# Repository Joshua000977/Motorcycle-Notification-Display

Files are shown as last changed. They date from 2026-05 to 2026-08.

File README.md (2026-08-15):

# Motorcycle Notification & TPMS Display

A compact motorcycle display system built around an ESP32-C3 and an Android application. It presents selected phone notifications, incoming-call information, phone battery status, and tire-pressure data on a handlebar-mounted TFT display.

The Android phone acts as the communication hub: it receives phone events and BLE TPMS data, filters and formats the relevant information, and forwards compact messages to the ESP32. The ESP32 handles parsing, warning logic, persistence, and display rendering.

> **Project status:** Active prototype. Phone-to-display BLE communication, notification rendering, and the embedded display foundation are implemented. TPMS integration and reliable background reconnection while the phone is locked are ongoing development areas.

## Features

### Implemented

- ESP32-C3 BLE peripheral named `MotoNotifyDisplay`
- Android-to-ESP32 BLE connection
- Display of selected phone notifications
- Incoming-call information
- Phone battery updates
- Compact custom text protocol
- TFT display rendering and idle screen
- Persistent configuration on the ESP32
- OTA firmware updates over Wi-Fi
- Tire-pressure warning states in the embedded display logic

### In Development

- Stable Android background operation through a foreground service
- Automatic reconnection when the ESP32 restarts while the phone is locked
- Simultaneous Android BLE connections to the ESP32 and both TPMS sensors
- Reliable pressure and temperature decoding for front and rear sensors
- Forwarding live TPMS data to the ESP32
- Android configuration UI for target pressures and warning thresholds
- Final weatherproof motorcycle enclosure and power installation

### Planned

- Per-app notification filters
- Multiple motorcycle profiles
- TPMS and temperature history
- External warning LEDs or audible alerts
- Navigation information
- Ride statistics

## System Overview

```mermaid
flowchart TD
    PHONE["Android phone"] --> APP["Android application"]
    FRONT["Front TPMS sensor"] --> APP
    REAR["Rear TPMS sensor"] --> APP
    APP --> ESP["ESP32-C3 display unit"]
    ESP --> TFT["TFT display"]
```

The phone handles Android permissions, notification access, calls, background execution, and BLE central connections. The ESP32 remains focused on receiving compact messages and presenting information clearly while riding.

See [docs/architecture.md](docs/architecture.md) for component responsibilities, BLE flows, message handling, reconnect behavior, and safety considerations.

## Hardware

| Component | Purpose |
|---|---|
| Seeed Studio ESP32-C3 SuperMini | BLE receiver and display controller |
| TFT display | Rider-facing interface |
| Front BLE TPMS sensor | Front pressure and temperature |
| Rear BLE TPMS sensor | Rear pressure and temperature |
| Android phone | Notification, call, TPMS, and BLE hub |
| Motorcycle power supply | Powers the embedded display unit |

## Technology

### Embedded Firmware

- C++
- Arduino framework
- PlatformIO
- NimBLE
- TFT_eSPI
- Persistent configuration storage
- Arduino OTA

### Android Application

- Kotlin
- Android BLE APIs
- `BluetoothGatt`
- `NotificationListenerService`
- Foreground-service architecture for reliable background communication
- Notification filtering and message formatting

### Communication

- Bluetooth Low Energy
- Custom text-based message protocol
- Android phone as BLE central
- ESP32-C3 as BLE peripheral

## BLE Message Protocol

The protocol uses short, human-readable messages. A prefix identifies the message type and the remaining text contains its value.

Examples:

```text
CALL:John Doe
NOTIFY:WhatsApp: Alex
BAT:58
FRONT:2.30
REAR:2.20
FTEMP:28
RTEMP:31
```

| Prefix | Meaning | Example value |
|---|---|---|
| `CALL` | Incoming call information | Caller name or number |
| `NOTIFY` | Selected notification | Application and message summary |
| `BAT` | Phone battery percentage | `58` |
| `FRONT` | Front tire pressure | `2.30` bar |
| `REAR` | Rear tire pressure | `2.20` bar |
| `FTEMP` | Front tire temperature | `28` °C |
| `RTEMP` | Rear tire temperature | `31` °C |

The text format is easy to inspect during development and simple to parse on the ESP32. A versioned binary protocol can be introduced later if message size or throughput becomes a real limitation.

## Tire-Pressure Warning Logic

Pressure warnings are calculated relative to configurable front and rear reference pressures.

Default reference values:

| Tire | Reference pressure |
|---|---:|
| Front | 2.5 bar |
| Rear | 2.8 bar |

| Status | Condition |
|---|---|
| Normal | Pressure is within the configured warning limits |
| Warning low | More than 10% below the reference pressure |
| Critical low | Front more than 15% low; rear more than 20% low |
| Warning high | More than 15% above the reference pressure |
| Critical high | More than 25% above the reference pressure |
| Critical | Pressure is less than or equal to 0 bar |

The display uses a simple color hierarchy:

| State | Color |
|---|---|
| Normal | White |
| Warning | Yellow |
| Critical | Red |

Reference pressures and thresholds must be configured for the motorcycle, tires, load, and manufacturer recommendations used in the real installation.

## Building the Firmware

1. Open the firmware project in Visual Studio Code with PlatformIO.
2. Select the configured ESP32-C3 environment.
3. Configure the display pins and TFT_eSPI setup for the installed hardware.
4. Build and upload the firmware over USB.
5. Configure Wi-Fi only if OTA updates are required.

After the first USB upload, later firmware versions can be installed through Arduino OTA when the device and development computer are on the same network.

## Building the Android Application

1. Open the Android project in Android Studio.
2. Grant the required Bluetooth and notification permissions.
3. Enable notification access for the application.
4. Build and install the application on the Android phone.
5. Connect the app to `MotoNotifyDisplay`.
6. Configure the front and rear TPMS sensors when TPMS support is enabled.

Android background restrictions vary between phone manufacturers. Foreground-service behavior, battery optimization, and BLE reconnection must be tested on the actual phone used on the motorcycle.

## Development Priorities

1. Finish the foreground service and locked-phone reconnection behavior.
2. Complete and verify both TPMS sensor connections.
3. Validate pressure and temperature values against known measurements.
4. Finish the Android configuration interface.
5. Improve display layouts and connection indicators.
6. Test reconnects, sensor loss, invalid values, and low battery conditions.
7. Build and validate the weatherproof motorcycle installation.

## Safety

This is a personal prototype and not a certified tire-pressure monitoring system. It should supplement, not replace:

- Manual pressure checks with a reliable gauge
- Motorcycle manufacturer pressure recommendations
- Regular tire inspection
- Approved motorcycle instruments and warning systems

The interface should not encourage interaction while riding. Alerts must be readable at a glance, and configuration should be performed while stationary.

## License

This project is licensed under the [MIT License](LICENSE)

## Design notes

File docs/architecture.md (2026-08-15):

# Architecture

This document describes the architecture of the Motorcycle Notification & TPMS Display. It separates the working embedded foundation from background-reconnection and TPMS functionality that is still being completed.

## 1. Design Goals

- Present essential information without requiring the rider to handle the phone.
- Keep the handlebar unit small and computationally simple.
- Use the Android phone for operating-system events and BLE sensor management.
- Keep the communication protocol easy to debug.
- Continue displaying the latest valid data when one source temporarily disconnects.
- Make warning states clear without creating unnecessary distraction.
- Allow the system to recover from phone, display, or sensor restarts.

## 2. System Context

```mermaid
flowchart TD
    EVENTS["Calls and notifications"] --> ANDROID["Android application"]
    TPMS["Front and rear TPMS"] --> ANDROID
    ANDROID --> ESP["ESP32-C3 firmware"]
    ESP --> DISPLAY["TFT display"]
```

The Android app is the central bridge. It combines Android system events and two BLE sensor connections into one application-level stream sent to the ESP32.

The ESP32 does not connect directly to the TPMS sensors. This avoids requiring the embedded unit to act as both a BLE peripheral for the phone and a BLE central for multiple sensors while also updating the display.

## 3. Component Responsibilities

### 3.1 Android Application

The Android application is responsible for:

- Receiving selected notifications through `NotificationListenerService`
- Detecting and formatting incoming-call information
- Filtering private or irrelevant notification content
- Maintaining the BLE connection to the ESP32
- Scanning for and connecting to front and rear TPMS sensors
- Subscribing to TPMS characteristics
- Decoding pressure, temperature, status, and battery data where available
- Forwarding normalized data to the ESP32
- Managing background execution and reconnect behavior
- Providing configuration for reference pressures and enabled applications

The Android app acts as a BLE central for all connections.

### 3.2 ESP32-C3 Display Unit

The ESP32 firmware is responsible for:

- Advertising the `MotoNotifyDisplay` BLE service
- Accepting an Android BLE connection
- Receiving framed application messages
- Parsing message prefixes and values
- Updating phone, call, notification, and TPMS state
- Calculating warning levels from configured pressure limits
- Rendering the correct screen or overlay
- Storing configuration values persistently
- Handling connection loss without crashing or blocking the display loop
- Supporting firmware updates over USB or OTA

The ESP32 is the authoritative component for the final visual warning state because it must continue rendering even if the phone briefly stops sending updates.

### 3.3 TPMS Sensors

Each tire uses an independent BLE sensor. Depending on the sensor protocol, values may be exposed through notifications, indications, or manufacturer-specific data.

Expected sensor data includes:

- Tire pressure
- Tire temperature
- Sensor battery level
- Sensor identity
- Availability or stale-data state

Raw sensor packets must be decoded and converted to consistent units before they are forwarded to the ESP32.

### 3.4 TFT Display

The display presents:

- Connection state
- Incoming-call overlay
- Selected notification overlay
- Front and rear pressure
- Front and rear temperature
- Warning and critical colors
- Phone battery state where useful

Display updates should be non-blocking so BLE events and reconnect logic remain responsive.

## 4. BLE Topology

```mermaid
flowchart LR
    FRONT["Front sensor"] --> PHONE["Android BLE central"]
    REAR["Rear sensor"] --> PHONE
    PHONE --> UNIT["ESP32 BLE peripheral"]
```

The Android device maintains three logical BLE relationships:

1. Android to ESP32 display unit
2. Android to front TPMS sensor
3. Android to rear TPMS sensor

Connections must be tracked independently. Losing one TPMS sensor must not disconnect the ESP32, and restarting the ESP32 must not unnecessarily discard valid TPMS sensor connections.

## 5. Data Flows

### 5.1 Notification Flow

```mermaid
sequenceDiagram
    participant OS as Android OS
    participant APP as Android app
    participant ESP as ESP32
    participant TFT as Display
    OS->>APP: Notification event
    APP->>APP: Filter and sanitize
    APP->>ESP: NOTIFY message
    ESP->>TFT: Render notification
```

The app should forward only explicitly enabled applications and the minimum information required for the display.

### 5.2 Call Flow

```mermaid
sequenceDiagram
    participant OS as Android OS
    participant APP as Android app
    participant ESP as ESP32
    participant TFT as Display
    OS->>APP: Incoming call state
    APP->>APP: Resolve allowed caller data
    APP->>ESP: CALL message
    ESP->>TFT: Render call overlay
```

Caller information should be cleared when the call ends so stale data does not remain on screen.

### 5.3 TPMS Flow

```mermaid
sequenceDiagram
    participant SENSOR as TPMS sensor
    participant APP as Android app
    participant ESP as ESP32
    participant TFT as Display
    SENSOR->>APP: BLE notification
    APP->>APP: Decode and normalize
    APP->>ESP: Pressure or temperature
    ESP->>ESP: Evaluate warning state
    ESP->>TFT: Update tire display
```

The app converts sensor-specific packets into stable protocol messages. The ESP32 therefore does not depend on the details of a particular TPMS sensor model.

## 6. Application Protocol

The current protocol uses UTF-8 text messages with a type prefix and colon separator.

```text
TYPE:value
```

Examples:

```text
CALL:John Doe
NOTIFY:WhatsApp: Alex
BAT:58
FRONT:2.30
REAR:2.20
FTEMP:28
RTEMP:31
```

### Parsing Rules

1. Read one complete BLE message.
2. Split at the first colon.
3. Treat the first part as the message type.
4. Keep the remainder as the payload so notification text may contain additional colons.
5. Validate numeric payloads before updating stored state.
6. Ignore unknown message types without crashing.

Malformed data must not overwrite the most recent valid pressure value.

### Possible Future Versioning

If the protocol expands significantly, a version prefix can be added:

```text
V1:FRONT:2.30
```

Protocol versioning should only be introduced when compatibility between released Android and firmware versions becomes difficult to manage.

## 7. Warning-State Calculation

The ESP32 calculates the final visual status from pressure, configured reference values, and stale-data state.

Default references:

| Tire | Reference |
|---|---:|
| Front | 2.5 bar |
| Rear | 2.8 bar |

Percentage thresholds:

| Status | Front | Rear |
|---|---|---|
| Warning low | More than 10% below reference | More than 10% below reference |
| Critical low | More than 15% below reference | More than 20% below reference |
| Warning high | More than 15% above reference | More than 15% above reference |
| Critical high | More than 25% above reference | More than 25% above reference |

Values less than or equal to zero are treated as critical or invalid rather than normal pressure readings.

Recommended evaluation order:

```text
Invalid or <= 0
-> Critical low/high
-> Warning low/high
-> Normal
```

The warning algorithm should also distinguish a real measured value from missing or stale sensor data. A disconnected sensor must not silently appear as a valid zero-pressure measurement unless the protocol explicitly reports that value.

## 8. State and Persistence

### Android State

The app tracks:

- ESP32 connection and `BluetoothGatt`
- Front sensor identity and connection
- Rear sensor identity and connection
- Last decoded sensor values
- Enabled notification applications
- Desired reference pressures
- Foreground-service lifecycle

### ESP32 State

The firmware tracks:

- BLE connection state
- Current display mode
- Latest call or notification
- Phone battery value
- Front and rear pressure
- Front and rear temperature
- Last update time for every tire
- Configured reference pressures and warning limits
- Current warning state

Persistent configuration should include only settings. Rapidly changing live measurements should normally remain in memory to avoid unnecessary flash writes.

## 9. Background Operation and Reconnection

Reliable locked-phone operation requires the BLE lifecycle to be owned by a foreground service rather than only an activity.

Target reconnect behavior:

```mermaid
stateDiagram-v2
    [*] --> Disconnected
    Disconnected --> Scanning: Retry allowed
    Scanning --> Connecting: Device found
    Connecting --> Connected: GATT ready
    Connecting --> Backoff: Failed
    Connected --> Backoff: Connection lost
    Backoff --> Scanning: Delay elapsed
```

Important rules:

- Only one active connection attempt should exist per device.
- Close obsolete `BluetoothGatt` objects before reconnecting.
- Use increasing retry delays to avoid a rapid reconnect loop.
- Keep the service alive with a visible Android notification.
- Handle Bluetooth being disabled and re-enabled.
- Restore connections after the ESP32 reboots while the phone is locked.
- Treat the two TPMS sensors and ESP32 as independent connection state machines.

This area requires testing on the real phone because Android power management differs between manufacturers.

## 10. Display State Model

A useful display priority is:

```text
Critical TPMS warning
-> Incoming call
-> Important notification
-> TPMS overview
-> Idle screen
```

The exact priority must balance urgency and distraction. A critical tire warning should not be hidden indefinitely by an ordinary notification.

Temporary overlays should expire automatically and return to the previous persistent screen.

## 11. Failure Handling

The system should handle the following conditions explicitly:

- Android application not connected
- ESP32 restarted
- Front sensor unavailable
- Rear sensor unavailable
- Both sensors unavailable
- Stale pressure value
- Invalid or malformed BLE message
- Phone Bluetooth disabled
- Display initialization failure
- OTA update interrupted

A failure in one data source should not stop unrelated information. For example, a missing rear TPMS sensor should not prevent incoming calls from being displayed.

## 12. Privacy and Security

- Notification access is highly sensitive and should be limited to selected applications.
- Full message contents should be optional.
- Caller information should not be stored longer than required.
- BLE commands that modify configuration should be validated.
- OTA updates should only be enabled on trusted networks.
- Wi-Fi credentials must not be committed to the repository.
- Debug logs should avoid printing private notification or caller content in release builds.

## 13. Physical and Electrical Considerations

The motorcycle installation must account for:

- Input-voltage conversion and electrical transients
- Ignition-switched power
- Weatherproof connectors and enclosure
- Vibration resistance
- Display readability in sunlight
- Glove-friendly or no-touch operation
- Secure mounting
- Cable strain relief
- Heat and condensation

The software should start automatically when power is applied and recover cleanly from sudden power loss.

## 14. Future Evolution

Possible future capabilities include:

- Versioned configuration messages
- Multiple motorcycle profiles
- Historical TPMS data stored on the phone
- Navigation instruction forwarding
- Ride statistics
- External warning LED or buzzer
- Configurable display themes
- Sensor battery warnings

New functions should preserve the main architecture: Android manages platform events and BLE peripherals, while the ESP32 provides a deterministic rider-facing display.

## 15. Safety Boundary

The project is an experimental supplemental display, not an approved automotive safety system. Pressure warnings depend on sensor accuracy, BLE availability, correct decoding, configuration, and software operation.

The rider remains responsible for manual tire inspection, verified pressure measurements, and following the motorcycle and tire manufacturers' recommendations.

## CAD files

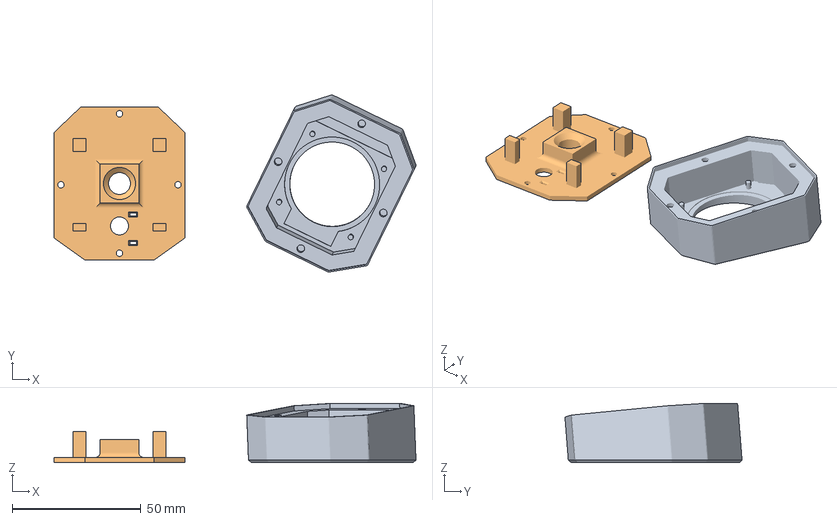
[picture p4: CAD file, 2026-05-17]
3D-Design/CL500/MotoNotify.3mf
140.8 x 68.9 x 23.0 mm
D_Case_Top
D_Case_Bottom_1

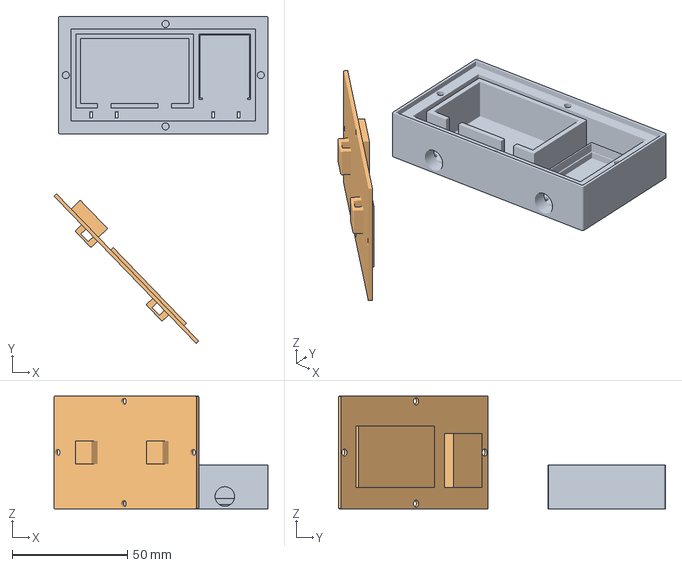
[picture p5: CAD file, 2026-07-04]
3D-Design/GL1800_SC47/EC.3mf
93.0 x 142.1 x 49.0 mm
Electronic_Case
EC_Top

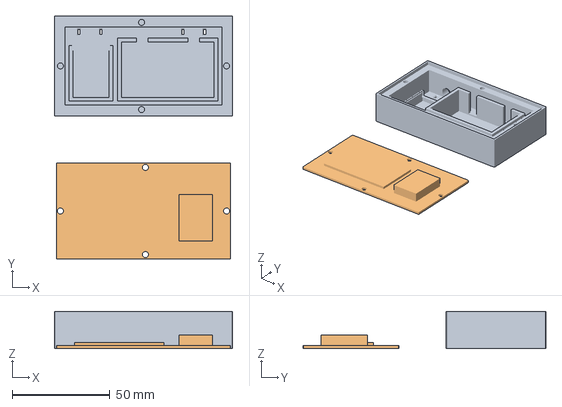
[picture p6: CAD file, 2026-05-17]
3D-Design/CL500/MotoNotifyEC.3mf
91.0 x 124.0 x 19.0 mm
Electronic_Case

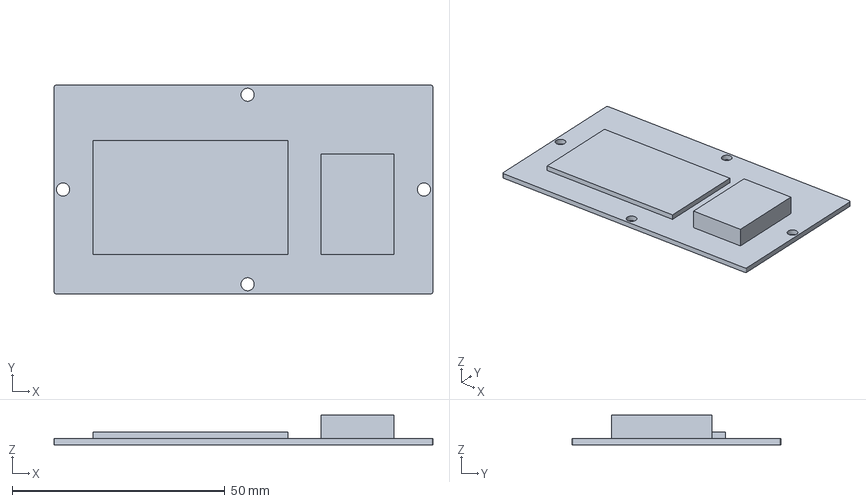
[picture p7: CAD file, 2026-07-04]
3D-Design/GL1800_SC47/EC_TOP.3mf
89.0 x 49.0 x 7.00 mm

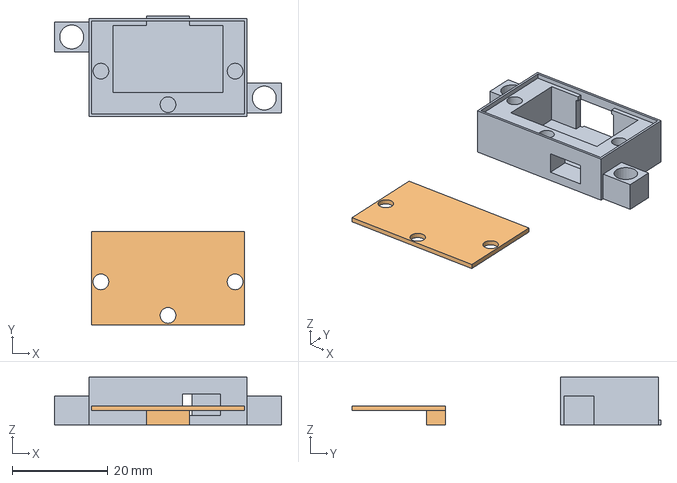
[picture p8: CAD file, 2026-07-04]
3D-Design/GL1800_SC47/USB_Case.3mf
47.4 x 64.5 x 10.0 mm

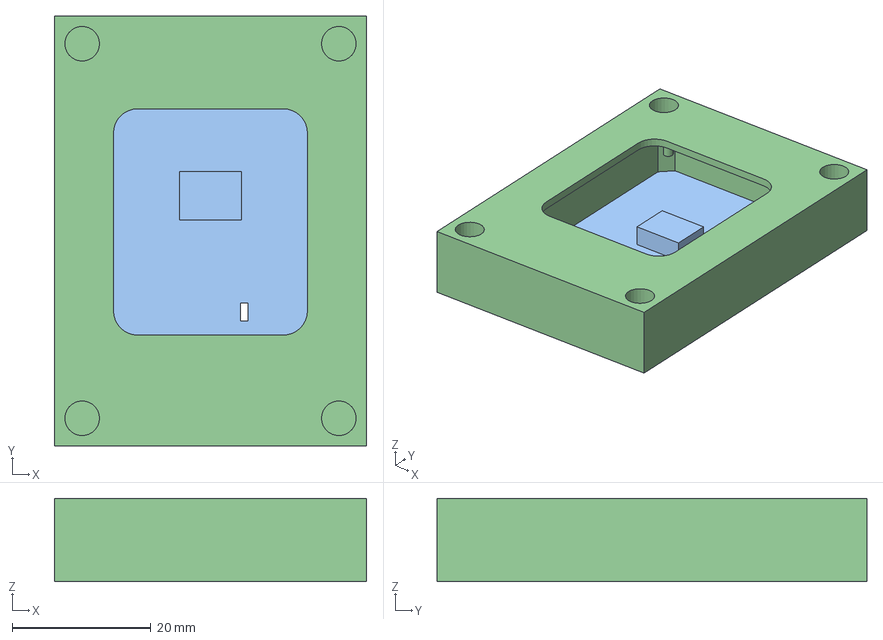
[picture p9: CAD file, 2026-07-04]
3D-Design/GL1800_SC47/DPC.3mf
45.0 x 62.0 x 12.0 mm
DPC_GL
DPC_GL_B
EC_Top

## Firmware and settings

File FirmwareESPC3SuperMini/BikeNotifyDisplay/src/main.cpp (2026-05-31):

#include <Arduino.h>
#include <NimBLEDevice.h>
#include <TFT_eSPI.h>
#include <WiFi.h>
#include <ArduinoOTA.h>
#include <Preferences.h>
Preferences prefs;

#define DEVICE_NAME "MotoNotifyDisplay"
#define SERVICE_UUID "6e400001-b5a3-f393-e0a9-e50e24dcca9e"
#define CHARACTERISTIC_UUID "6e400002-b5a3-f393-e0a9-e50e24dcca9e"

TFT_eSPI tft = TFT_eSPI();

NimBLEServer *bleServer = nullptr;
NimBLECharacteristic *rxCharacteristic = nullptr;
NimBLEAdvertisedDevice *findTpmsDevice(const char *targetMac);

// OTA
String wifiSSID = "";
String wifiPassword = "";
/*for platformio.ini
upload_protocol = espota
upload_port = 10.168.122.34
*/

bool wifiConnected = false;

void connectToWiFi();
void setupOTA();

unsigned long lastNotificationTime = 0;
bool showingNotification = false;
String currentText = "";
bool scrollingText = false;

int scrollX = 0;
int textWidth = 0;

unsigned long lastScrollUpdate = 0;
int scrollLoops = 0;
uint16_t currentTextColor = TFT_WHITE;

struct TpmsData
{
    float pressureBar = 0.0f;
    float temperatureC = 0.0f;
    int batteryPercent = -1;
    bool connected = false;
};

float frontPressure = -1.0f;
float rearPressure = -1.0f;
TpmsData frontTpms;
TpmsData rearTpms;

static NimBLEClient *frontClient = nullptr;
static NimBLEClient *rearClient = nullptr;
const char *FRONT_SENSOR_MAC = "08:35:1B:02:43:CC";
const char *REAR_SENSOR_MAC = "08:35:1B:02:43:73";

int mobileBatLvl = -1;

bool deviceConnected = false;
void handleNotification(const String &message);
void drawIdleScreen();
void showScrollingOrCenteredText(const String &text, uint16_t color);
void handleTpmsPacket(uint8_t *data, size_t len, TpmsData &tpms);
void handleBatteryPacket(uint8_t *data, size_t len, TpmsData &tpms);
void tpmsNotifyCallback(
    NimBLERemoteCharacteristic *characteristic,
    uint8_t *data,
    size_t length,
    bool isNotify);
bool connectTpmsSensor(
    const char *mac,
    NimBLEClient *&client);
NimBLEAdvertisedDevice *findTpmsDevice(const char *targetMac)
{
    Serial.println();
    Serial.println("========== TPMS SCAN START ==========");
    Serial.print("Target MAC: ");
    Serial.println(targetMac);
    Serial.print("Phone connected: ");
    Serial.println(deviceConnected ? "YES" : "NO");

    bool wasConnectedToPhone = deviceConnected;

    if (!wasConnectedToPhone)
    {
        Serial.println("Stopping ESP32 advertising before scan...");
        NimBLEDevice::stopAdvertising();
        delay(1000);
    }
    else
    {
        Serial.println("Phone is connected. Scan may be weaker.");
    }

    NimBLEScan *scan = NimBLEDevice::getScan();

    scan->setActiveScan(true);
    scan->setInterval(160);
    scan->setWindow(150);

    Serial.println("Scan settings:");
    Serial.println("Active scan: true");
    Serial.println("Interval: 160");
    Serial.println("Window: 150");
    Serial.println("Total scan time: up to 60 seconds");

    tft.fillScreen(TFT_BLACK);
    tft.setTextDatum(MC_DATUM);
    tft.setTextColor(TFT_WHITE, TFT_BLACK);
    tft.drawString("TPMS SCAN", 120, 45, 4);
    tft.drawString(targetMac, 120, 85, 2);
    tft.drawString("MOVE SENSOR", 120, 125, 2);

    for (int round = 1; round <= 6; round++)
    {
        Serial.println();
        Serial.print("----- Scan round ");
        Serial.print(round);
        Serial.println("/6 -----");

        tft.fillScreen(TFT_BLACK);
        tft.setTextDatum(MC_DATUM);
        tft.setTextColor(TFT_WHITE, TFT_BLACK);
        tft.drawString("SCAN " + String(round) + "/6", 120, 50, 4);
        tft.drawString("WAIT 10 SEC", 120, 95, 2);
        tft.drawString("MOVE TPMS", 120, 130, 2);

        NimBLEScanResults results = scan->getResults(10, false);

        int count = results.getCount();

        Serial.print("BLE devices found this round: ");
        Serial.println(count);

        tft.fillScreen(TFT_BLACK);
        tft.setTextDatum(MC_DATUM);
        tft.setTextColor(TFT_WHITE, TFT_BLACK);
        tft.drawString("ROUND " + String(round), 120, 40, 4);
        tft.drawString("FOUND: " + String(count), 120, 85, 4);

        delay(1000);

        for (int i = 0; i < count; i++)
        {
            const NimBLEAdvertisedDevice *device = results.getDevice(i);

            String foundMac = device->getAddress().toString().c_str();
            String name = device->getName().c_str();

            bool macMatch = foundMac.equalsIgnoreCase(targetMac);
            bool nameMatch = false;

            if (String(targetMac).endsWith(":CC"))
            {
                nameMatch = name.indexOf("0243CC") >= 0 || name.indexOf("43CC") >= 0 || name.indexOf("RT") >= 0;
            }
            else if (String(targetMac).endsWith(":73"))
            {
                nameMatch = name.indexOf("024373") >= 0 || name.indexOf("4373") >= 0 || name.indexOf("RT") >= 0;
            }

            Serial.println();
            Serial.println("---------- BLE DEVICE ----------");
            Serial.print("Round: ");
            Serial.println(round);

            Serial.print("Index: ");
            Serial.print(i + 1);
            Serial.print("/");
            Serial.println(count);

            Serial.print("MAC: ");
            Serial.println(foundMac);

            Serial.print("Target MAC match: ");
            Serial.println(macMatch ? "YES" : "NO");

            Serial.print("Name match: ");
            Serial.println(nameMatch ? "YES" : "NO");

            Serial.print("RSSI: ");
            Serial.println(device->getRSSI());

            Serial.print("Name: ");
            if (name.length() > 0)
            {
                Serial.println(name);
            }
            else
            {
                Serial.println("<no name>");
            }

            Serial.print("Address type: ");
            Serial.println((int)device->getAddress().getType());

            Serial.print("Has service UUID: ");
            Serial.println(device->haveServiceUUID() ? "YES" : "NO");

            if (device->haveServiceUUID())
            {
                Serial.print("Service UUID: ");
                Serial.println(device->getServiceUUID().toString().c_str());
            }

            Serial.print("Has manufacturer data: ");
            Serial.println(device->haveManufacturerData() ? "YES" : "NO");

            if (device->haveManufacturerData())
            {
                std::string manufacturerData = device->getManufacturerData();

                Serial.print("Manufacturer data length: ");
                Serial.println(manufacturerData.length());

                Serial.print("Manufacturer HEX: ");

                for (size_t j = 0; j < manufacturerData.length(); j++)
                {
                    uint8_t b = (uint8_t)manufacturerData[j];

                    if (b < 16)
                    {
                        Serial.print("0");
                    }

                    Serial.print(b, HEX);
                    Serial.print(" ");
                }

                Serial.println();
            }

            Serial.print("Has service data: ");
            Serial.println(device->haveServiceData() ? "YES" : "NO");

            if (device->haveServiceData())
            {
                std::string serviceData = device->getServiceData();

                Serial.print("Service data length: ");
                Serial.println(serviceData.length());

                Serial.print("Service data HEX: ");

                for (size_t j = 0; j < serviceData.length(); j++)
                {
                    uint8_t b = (uint8_t)serviceData[j];

                    if (b < 16)
                    {
                        Serial.print("0");
                    }

                    Serial.print(b, HEX);
                    Serial.print(" ");
                }

                Serial.println();
            }

            tft.fillScreen(TFT_BLACK);
            tft.setTextDatum(MC_DATUM);
            tft.setTextColor((macMatch || nameMatch) ? TFT_GREEN : TFT_YELLOW, TFT_BLACK);

            if (macMatch)
            {
                tft.drawString("MAC MATCH", 120, 25, 4);
            }
            else if (nameMatch)
            {
                tft.drawString("NAME MATCH", 120, 25, 4);
            }
            else
            {
                tft.drawString("NO MATCH", 120, 25, 4);
            }

            tft.setTextColor(TFT_WHITE, TFT_BLACK);
            tft.drawString(foundMac, 120, 70, 2);
            tft.drawString("RSSI " + String(device->getRSSI()), 120, 105, 2);

            if (name.length() > 0)
            {
                tft.drawString(name, 120, 140, 2);
            }
            else
            {
                tft.drawString("NO NAME", 120, 140, 2);
            }

            delay(1500);

            if (macMatch || nameMatch)
            {
                Serial.println();
                Serial.println("Target TPMS found.");
                Serial.print("Found by: ");
                Serial.println(macMatch ? "MAC" : "NAME");
                Serial.println("Returning advertised device copy for connection...");

                tft.fillScreen(TFT_BLACK);
                tft.setTextDatum(MC_DATUM);
                tft.setTextColor(TFT_GREEN, TFT_BLACK);
                tft.drawString("TPMS FOUND", 120, 80, 4);
                tft.drawString(foundMac, 120, 120, 2);

                NimBLEAdvertisedDevice *copy = new NimBLEAdvertisedDevice(*device);

                scan->clearResults();

                Serial.println("========== TPMS SCAN END: FOUND ==========");
                return copy;
            }
        }

        scan->clearResults();

        Serial.println("Target not found in this round.");

        tft.fillScreen(TFT_BLACK);
        tft.setTextDatum(MC_DATUM);
        tft.setTextColor(TFT_YELLOW, TFT_BLACK);
        tft.drawString("NO TPMS", 120, 60, 4);
        tft.drawString("ROUND " + String(round) + "/6", 120, 105, 2);

        delay(1000);
    }

    if (!wasConnectedToPhone)
    {
        Serial.println("Restarting ESP32 advertising after scan...");
        NimBLEDevice::startAdvertising();
    }

    Serial.println();
    Serial.println("Target TPMS was NOT found after 60 seconds.");
    Serial.println("========== TPMS SCAN END: NOT FOUND ==========");

    tft.fillScreen(TFT_BLACK);
    tft.setTextDatum(MC_DATUM);
    tft.setTextColor(TFT_RED, TFT_BLACK);
    tft.drawString("NOT FOUND", 120, 60, 4);
    tft.drawString(targetMac, 120, 105, 2);
    tft.drawString("60 SEC FAIL", 120, 140, 2);

    delay(3000);

    return nullptr;
}

void tpmsNotifyCallback(
    NimBLERemoteCharacteristic *characteristic,
    uint8_t *data,
    size_t length,
    bool isNotify)
{
    Serial.println();
    Serial.println("========== TPMS NOTIFY ==========");

    Serial.print("Notify: ");
    Serial.println(isNotify ? "YES" : "NO");

    Serial.print("Length: ");
    Serial.println(length);

    Serial.print("Raw HEX: ");

    for (size_t i = 0; i < length; i++)
    {
        if (data[i] < 16)
        {
            Serial.print("0");
        }

        Serial.print(data[i], HEX);
        Serial.print(" ");
    }

    Serial.println();

    if (length < 2)
    {
        Serial.println("Packet too short. Ignoring.");
        Serial.println("========== TPMS NOTIFY END ==========");
        return;
    }

    float temperature = data[0] - 40.0f;
    float pressure = data[1] / 40.0f;

    String mac =
        characteristic->getRemoteService()
            ->getClient()
            ->getPeerAddress()
            .toString()
            .c_str();

    Serial.print("Peer MAC: ");
    Serial.println(mac);

    Serial.print("Temperature: ");
    Serial.print(temperature);
    Serial.println(" C");

    Serial.print("Pressure: ");
    Serial.print(pressure);
    Serial.println(" bar");

    if (mac.equalsIgnoreCase(FRONT_SENSOR_MAC))
    {
        Serial.println("Sensor: FRONT");

        frontPressure = pressure;
        frontTpms.temperatureC = temperature;
        frontTpms.pressureBar = pressure;
        frontTpms.connected = true;
    }
    else if (mac.equalsIgnoreCase(REAR_SENSOR_MAC))
    {
        Serial.println("Sensor: REAR");

        rearPressure = pressure;
        rearTpms.temperatureC = temperature;
        rearTpms.pressureBar = pressure;
        rearTpms.connected = true;
    }
    else
    {
        Serial.println("Sensor: UNKNOWN MAC");
    }

    Serial.println("========== TPMS NOTIFY END ==========");

    if (!showingNotification && !wifiConnected)
    {
        drawIdleScreen();
    }
}
bool connectTpmsSensor(
    const char *mac,
    NimBLEClient *&client)
{
    Serial.println();
    Serial.println("========== TPMS CONNECT START ==========");
    Serial.print("Target MAC: ");
    Serial.println(mac);

    tft.fillScreen(TFT_BLACK);
    tft.setTextDatum(MC_DATUM);
    tft.drawString("CONNECTING", 120, 80, 2);
    tft.drawString(mac, 120, 120, 2);

    NimBLEAdvertisedDevice *tpmsDevice = findTpmsDevice(mac);

    if (tpmsDevice == nullptr)
    {
        Serial.println("Result: target was not found during scan.");
        Serial.println("========== TPMS CONNECT END: NOT FOUND ==========");

        tft.fillScreen(TFT_BLACK);
        tft.setTextDatum(MC_DATUM);
        tft.setTextColor(TFT_RED, TFT_BLACK);
        tft.drawString("NOT FOUND", 120, 80, 4);
        tft.drawString(mac, 120, 120, 2);

        delay(3000);

        return false;
    }

    Serial.println("Creating BLE client...");
    client = NimBLEDevice::createClient();
    client->setConnectTimeout(10);

    Serial.println("Client created.");
    Serial.println("Client connect timeout: 10 seconds");

    Serial.print("Connecting to discovered TPMS: ");
    Serial.println(mac);

    bool connected = client->connect(tpmsDevice);

    Serial.print("Connect result: ");
    Serial.println(connected ? "SUCCESS" : "FAILED");

    if (!connected)
    {
        Serial.println("Connection failed.");
        Serial.print("Client still connected: ");
        Serial.println(client->isConnected() ? "YES" : "NO");

        delete tpmsDevice;

        if (client)
        {
            Serial.println("Deleting failed BLE client...");
            NimBLEDevice::deleteClient(client);
            client = nullptr;
        }

        NimBLEDevice::startAdvertising();

        tft.fillScreen(TFT_BLACK);
        tft.setTextDatum(MC_DATUM);
        tft.setTextColor(TFT_RED, TFT_BLACK);
        tft.drawString("CONNECT FAIL", 120, 55, 4);
        tft.drawString(mac, 120, 95, 2);
        tft.drawString("SEE SERIAL", 120, 135, 2);

        delay(3000);

        Serial.println("========== TPMS CONNECT END: FAILED ==========");

        return false;
    }

    delete tpmsDevice;

    Serial.println("Connected to TPMS.");

    tft.fillScreen(TFT_BLACK);
    tft.setTextDatum(MC_DATUM);
    tft.setTextColor(TFT_GREEN, TFT_BLACK);
    tft.drawString("CONNECTED", 120, 80, 4);
    tft.drawString(mac, 120, 120, 2);

    delay(1000);

    Serial.println("Searching service FFD0...");
    auto service = client->getService("FFD0");

    if (!service)
    {
        Serial.println("Service FFD0 not found.");
        Serial.println("Trying full UUID 0000ffd0-0000-1000-8000-00805f9b34fb...");

        service = client->getService("0000ffd0-0000-1000-8000-00805f9b34fb");
    }

    if (!service)
    {
        Serial.println("Service FFD0 not found with both formats.");

        tft.fillScreen(TFT_BLACK);
        tft.setTextColor(TFT_RED, TFT_BLACK);
        tft.drawString("NO FFD0", 120, 120, 4);

        delay(3000);

        Serial.println("========== TPMS CONNECT END: NO SERVICE ==========");

        return false;
    }

    Serial.println("Service FFD0 found.");

    Serial.println("Searching characteristic FFD1...");
    auto characteristic = service->getCharacteristic("FFD1");

    if (!characteristic)
    {
        Serial.println("Characteristic FFD1 not found.");
        Serial.println("Trying full UUID 0000ffd1-0000-1000-8000-00805f9b34fb...");

        characteristic = service->getCharacteristic("0000ffd1-0000-1000-8000-00805f9b34fb");
    }

    if (!characteristic)
    {
        Serial.println("Characteristic FFD1 not found with both formats.");

        tft.fillScreen(TFT_BLACK);
        tft.setTextColor(TFT_RED, TFT_BLACK);
        tft.drawString("NO FFD1", 120, 120, 4);

        delay(3000);

        Serial.println("========== TPMS CONNECT END: NO CHARACTERISTIC ==========");

        return false;
    }

    Serial.println("Characteristic FFD1 found.");

    Serial.print("FFD1 canRead: ");
    Serial.println(characteristic->canRead() ? "YES" : "NO");

    Serial.print("FFD1 canNotify: ");
    Serial.println(characteristic->canNotify() ? "YES" : "NO");

    Serial.print("FFD1 canIndicate: ");
    Serial.println(characteristic->canIndicate() ? "YES" : "NO");

    Serial.print("FFD1 canWrite: ");
    Serial.println(characteristic->canWrite() ? "YES" : "NO");

    tft.fillScreen(TFT_BLACK);
    tft.setTextColor(TFT_GREEN, TFT_BLACK);
    tft.drawString("FFD1 FOUND", 120, 120, 4);

    delay(1000);

    if (characteristic->canNotify())
    {
        Serial.println("Subscribing to FFD1 notifications...");

        bool subOk = characteristic->subscribe(true, tpmsNotifyCallback);

        Serial.print("Subscribe result: ");
        Serial.println(subOk ? "SUCCESS" : "FAILED");

        tft.fillScreen(TFT_BLACK);
        tft.setTextColor(subOk ? TFT_GREEN : TFT_RED, TFT_BLACK);
        tft.drawString(subOk ? "SUBSCRIBED" : "SUB FAIL", 120, 120, 4);

        delay(1000);
    }
    else
    {
        Serial.println("FFD1 does not support notify.");
    }

    if (characteristic->canRead())
    {
        Serial.println("Reading FFD1 value...");

        auto value = characteristic->readValue();

        Serial.print("Read length: ");
        Serial.println(value.size());

        Serial.print("Read HEX: ");

        for (size_t i = 0; i < value.size(); i++)
        {
            uint8_t b = (uint8_t)value[i];

            if (b < 16)
            {
                Serial.print("0");
            }

            Serial.print(b, HEX);
            Serial.print(" ");
        }

        Serial.println();

        tft.fillScreen(TFT_BLACK);
        tft.setTextColor(TFT_WHITE, TFT_BLACK);

        if (value.size() >= 2)
        {
            uint8_t tempRaw = (uint8_t)value[0];
            uint8_t pressureRaw = (uint8_t)value[1];

            float temperature = tempRaw - 40.0f;
            float pressure = pressureRaw / 40.0f;

            Serial.print("Temp raw: ");
            Serial.println(tempRaw);

            Serial.print("Pressure raw: ");
            Serial.println(pressureRaw);

            Serial.print("Temperature decoded: ");
            Serial.print(temperature);
            Serial.println(" C");

            Serial.print("Pressure decoded: ");
            Serial.print(pressure);
            Serial.println(" bar");

            if (String(mac).equalsIgnoreCase(FRONT_SENSOR_MAC))
            {
                frontPressure = pressure;
                frontTpms.temperatureC = temperature;
                frontTpms.pressureBar = pressure;
                frontTpms.connected = true;
            }
            else if (String(mac).equalsIgnoreCase(REAR_SENSOR_MAC))
            {
                rearPressure = pressure;
                rearTpms.temperatureC = temperature;
                rearTpms.pressureBar = pressure;
                rearTpms.connected = true;
            }

            tft.drawString("PRESSURE", 120, 90, 2);
            tft.drawString(String(pressure, 1) + " bar", 120, 130, 4);

            delay(3000);
        }
        else
        {
            Serial.println("Read value too short or empty.");

            tft.drawString("NO DATA", 120, 120, 4);

            delay(3000);
        }
    }
    else
    {
        Serial.println("FFD1 does not support read.");
    }

    NimBLEDevice::startAdvertising();

    Serial.println("========== TPMS CONNECT END: SUCCESS ==========");

    return true;
}

enum class PressureState
{
    OK,
    WARNING,
    CRITICAL
};

PressureState getPressureState(float pressure)
{
    if (pressure <= 0)
        return PressureState::CRITICAL;

    if (pressure < 1.8f)
        return PressureState::CRITICAL;

    if (pressure < 2.0f)
        return PressureState::WARNING;

    if (pressure > 3.2f)
        return PressureState::CRITICAL;

    if (pressure > 2.9f)
        return PressureState::WARNING;

    return PressureState::OK;
}
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
void loop()
{
    if (wifiConnected)
    {

        ArduinoOTA.handle();
    }

    static bool lastConnectionState = false;
    // Return to idle screen after 10 seconds
    if (showingNotification && millis() - lastNotificationTime > 10000)
    {
        showingNotification = false;
        drawIdleScreen();
    }

    // Update idle screen when connection state changes
    if (!showingNotification && lastConnectionState != deviceConnected && !wifiConnected)
    {
        lastConnectionState = deviceConnected;
        drawIdleScreen();
    }

    if (scrollingText && !wifiConnected)
    {
        if (millis() - lastScrollUpdate > 50)
        {
            lastScrollUpdate = millis();

            tft.fillRect(0, 80, 240, 80, TFT_BLACK);

            tft.setTextColor(currentTextColor, TFT_BLACK);

            tft.setTextDatum(TL_DATUM);

            tft.setTextSize(2);

            tft.drawString(currentText, scrollX, 100, 4);

            scrollX--;

            if (scrollX < -textWidth)
            {
                scrollLoops++;

                if (scrollLoops >= 2)
                {
                    scrollingText = false;
                    showingNotification = false;
                    drawIdleScreen();
                }
                else
                {
                    scrollX = 10;
                }
            }
        }
    }
}

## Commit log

2026-05-09 First prototype. Simple BLE Connection and sending test messages to the espc3
2026-05-10 Implement automatic device scanning and reconnect
2026-05-17 3d design
    added 3d design
    [MotoNotify.3mf, MotoNotifyEC.3mf]
2026-05-30 added placeholder for tire pressure and phone bat level
2026-05-30 Handle phone battery BLE messages"
2026-05-30 Add phone battery monitoring and reporter to BleManager
2026-05-31 testign no connection to sensors
2026-05-31 Implement TPMS sensor monitoring and reporting
    - Introduce `TpmsBleManager` to manage RiDEET Pro TPMS sensors, including scanning, connecting, and decoding pressure and temperature data.
    - Add `TpmsBleManagerProvider` to manage the singleton instance of the TPMS manager.
    - Integrate TPMS lifecycle management into `ForegroundBleService` to handle periodic sensor reads in the background.
    - Implement automatic forwarding of TPMS data to the MotoNotify display via `BleManager`.
    - Update `MainActivity` with a `TpmsStatusCard` UI component to display real-time sensor status, pressure, and temperature.
    - Add support for Bluetooth permission and state checking specifically for TPMS operations.
2026-05-31 Add battery level monitoring for TPMS sensors
    - Update `TpmsSensorState` and UI components to track and display battery percentage.
    - Implement reading of the standard Battery Level characteristic (0x2A19) during the TPMS sensor polling cycle.
    - Add `decodeBatteryLevel` utility to parse battery data from the peripheral.
    - Extend `sendToEsp32` to forward front and rear sensor battery levels to the ESP32 display via the `TPMSFB` and `TPMSRB` prefixes.
    - Refactor TPMS read logic to handle potential failures in specific characteristic reads without failing the entire cycle.
2026-05-31 Remove TPMS battery monitoring and improve sensor reading reliability
    - Remove battery level tracking and display from `TpmsBleManager`, `MainActivity`, and ESP32 communication.
    - Implement a retry mechanism (3 attempts) for reading the TPMS data characteristic.
    - Add a notification fallback to capture TPMS data if direct reads fail or return invalid payloads.
    - Introduce `isValidTpmsPayload` to filter out malformed or empty BLE data.
    - Add a post-connection settle delay and increased read timeouts to improve connection stability.
    - Simplify `TpmsSensorState` and UI components to focus on pressure and temperature.
2026-07-04 Added all .3mf files
    [DPC.3mf, EC.3mf, EC_TOP.3mf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]
